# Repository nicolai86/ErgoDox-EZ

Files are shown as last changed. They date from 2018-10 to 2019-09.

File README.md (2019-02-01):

# ErgoDox-EZ

[ErgoDox EZ](https://ergodox-ez.com/) LED mod to convert your regular ErgoDox EZ into an ErgoDox EZ shine.  
The total cost for this mod is about about 40 CAD (~30 CAD for PCBs, ~10 CAD for components)

## Instructions

To build this mod you need to assemble two LED strips, and one I2C bridge. The LED strips are installed on both sides. The right hand LED strip is directly connected to the main PCB. The left hand LED strip requires an I2C bridge to function.

## Firmware

Once you've connected your Atmega168 you can compile the firmware and flash your microcontroller with the included makefile:

```
$ make build
$ make flash
```

The makefile is setup to use the AVR ISP MKII.

## LED strip

You will need to LED pcbs to build this mod. The LED strips are identical for both sides.

### List of materials

| Component | Amount | Notes |
|---|:---:|---:|
| RGBW6812  | 30 | 15 per side; Can be ordered at Aliexpress |
| 3-pin micro JST connector | 1 | right hand connector to main PCB |

The gerber files, eagle project schematics and board files are included in the led-strip folder.

### Assembly

The LED strip assembly needs to be done twice, once for each half. For each side:

1. Solder all 15 RGBW SK6812 LEDs 
2. Solder the cables according to the marks

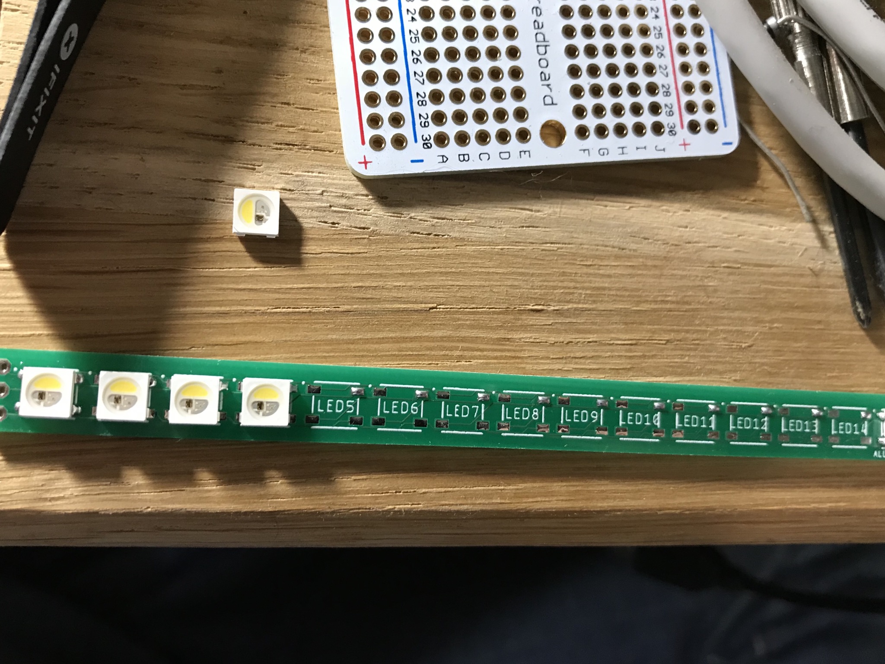
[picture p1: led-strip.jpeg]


For the right hand you can solder the cables to the keyboard, or use a 3-pin micro JST connector instead.
The left hand needs to be connected to an I2C bridge:

## I2C bridge

### List of materials

| Component | Amount | Notes |
|---|:---:|---:|
| atmega168pa-au  | 1 | Required to decode I2C traffic |
| 0805 22pF cap | 2 | |
| 0805 10uF cap | 1 | |
| 0805 10K resistor | 3 | |
| CSM-7X-DU 16Mhz oscillator | 1 | |
| 6 pin AVR ISP connector | 1 | |
| 4-pin micro JST connector | 1 | left hand connector to main PCB |

The gerber files, eagle project schematics and board files are included in the i2c-bride folder.

## Assembly

1. Solder the Atmega168p. Make sure to align the dark circle with the PCB properly. I've used SMD solder paste to place a film over all pins, solder one pin at a time.
2. Solder the 2 22pF caps, C3 and C2.
3. Solder the oscillator. 
4. Solder the 10uF cap.
5. Solder the 3 10k res.
6. Solder the jack. Note that you'll need to desolder it after flashing, or cut them off.

The left hand will look like this after soldering:

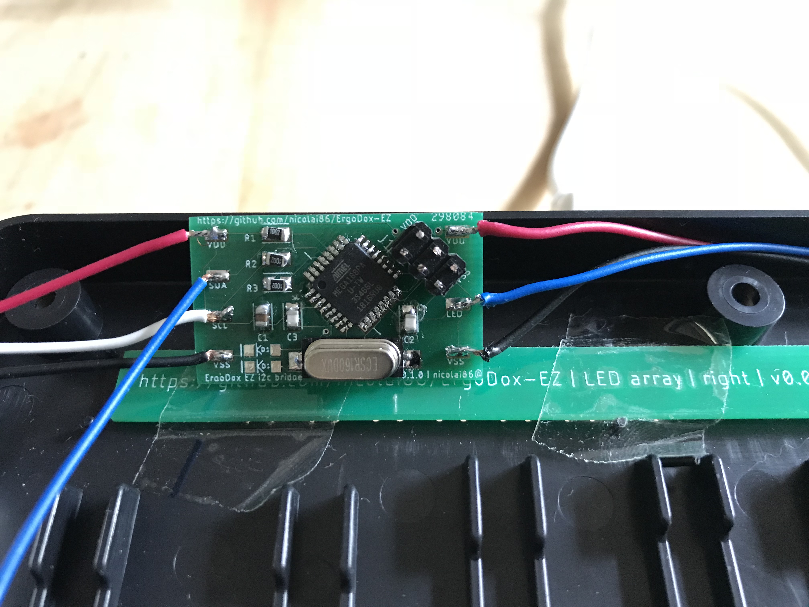
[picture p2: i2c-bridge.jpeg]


check out [KeebTalk](https://www.keebtalk.com/t/did-anybody-try-to-mod-their-ergodox-ez-with-a-custom-led-array/2286) for more images.

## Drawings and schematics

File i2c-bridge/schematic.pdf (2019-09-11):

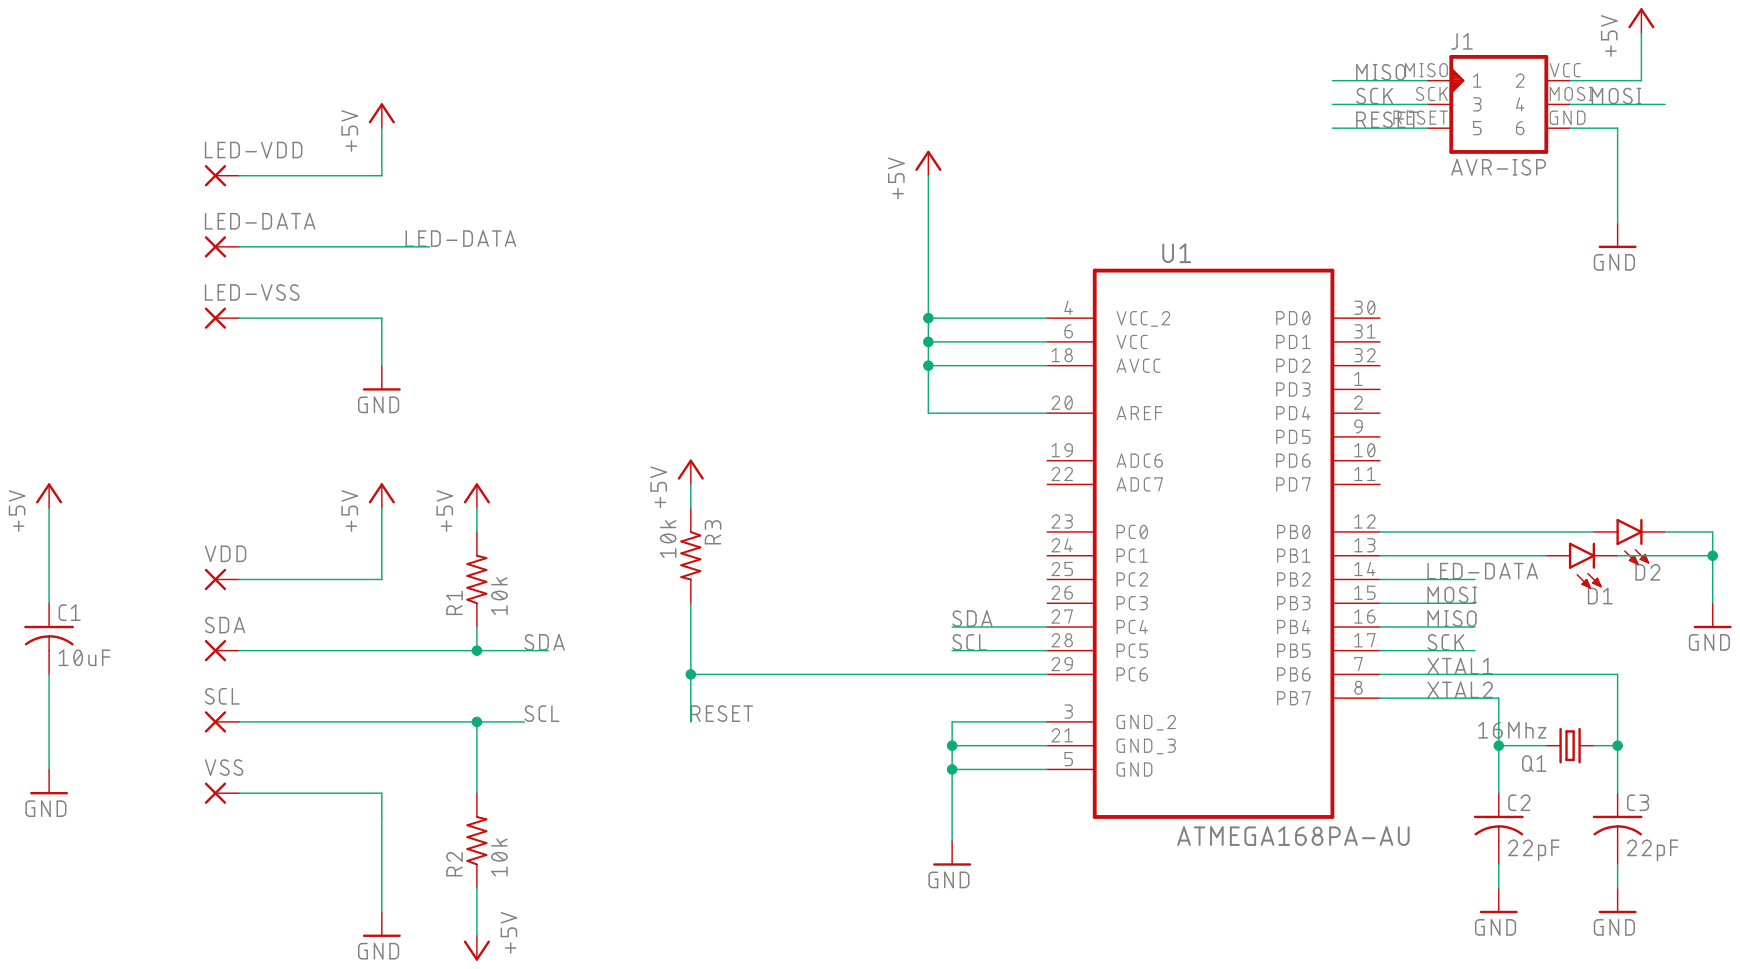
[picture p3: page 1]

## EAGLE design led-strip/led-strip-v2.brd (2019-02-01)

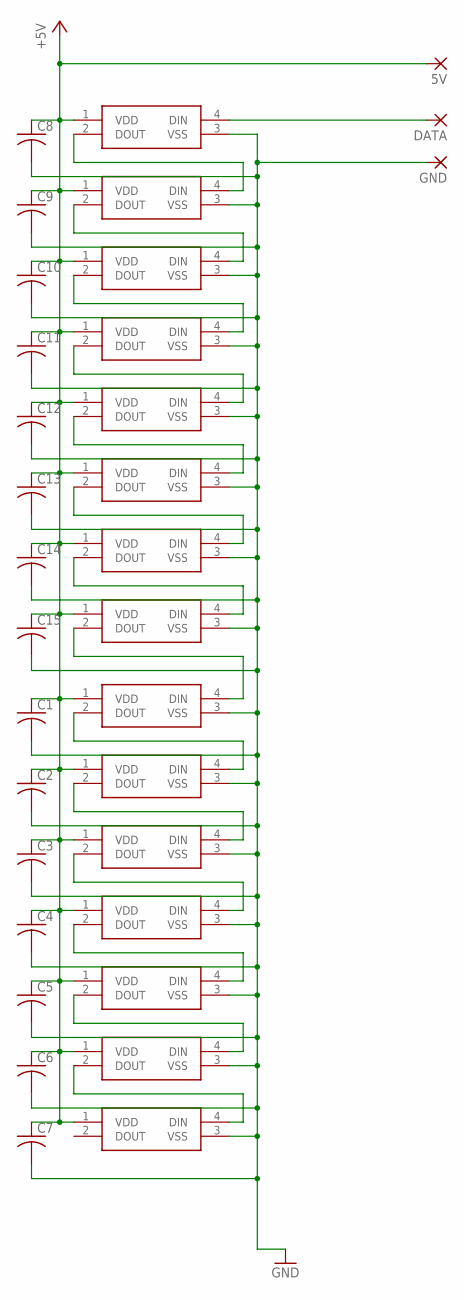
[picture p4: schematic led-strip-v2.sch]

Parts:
5V: 1,6/0,8
C1, C2, C3, C4, C5, C6, C7, C8, C9, C10, C11, C12, C13, C14, C15: C-USC0805; C0805
DATA: 1,6/0,8
GND: 1,6/0,8
LED1, LED2, LED3, LED4, LED5, LED6, LED7, LED8, LED9, LED10, LED11, LED12, LED13, LED14, LED15: 1655; WS2812B_1

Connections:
+5V: 5V.1, C1.1, C2.1, C3.1, C4.1, C5.1, C6.1, C7.1, C8.1, C9.1, C10.1, C11.1, C12.1, C13.1, C14.1, C15.1, LED1.1 (VDD), LED2.1 (VDD), LED3.1 (VDD), LED4.1 (VDD), LED5.1 (VDD), LED6.1 (VDD), LED7.1 (VDD), LED8.1 (VDD), LED9.1 (VDD), LED10.1 (VDD), LED11.1 (VDD), LED12.1 (VDD), LED13.1 (VDD), LED14.1 (VDD), LED15.1 (VDD)
DATA-IN: DATA.1, LED1.4 (DIN)
GND: C1.2, C2.2, C3.2, C4.2, C5.2, C6.2, C7.2, C8.2, C9.2, C10.2, C11.2, C12.2, C13.2, C14.2, C15.2, GND.1, LED1.3 (VSS), LED2.3 (VSS), LED3.3 (VSS), LED4.3 (VSS), LED5.3 (VSS), LED6.3 (VSS), LED7.3 (VSS), LED8.3 (VSS), LED9.3 (VSS), LED10.3 (VSS), LED11.3 (VSS), LED12.3 (VSS), LED13.3 (VSS), LED14.3 (VSS), LED15.3 (VSS)
unnamed: LED1.2 (DOUT), LED2.4 (DIN)
unnamed: LED2.2 (DOUT), LED3.4 (DIN)
unnamed: LED3.2 (DOUT), LED4.4 (DIN)
unnamed: LED4.2 (DOUT), LED5.4 (DIN)
unnamed: LED5.2 (DOUT), LED6.4 (DIN)
unnamed: LED6.2 (DOUT), LED7.4 (DIN)
unnamed: LED7.2 (DOUT), LED8.4 (DIN)
unnamed: LED8.2 (DOUT), LED9.4 (DIN)
unnamed: LED9.2 (DOUT), LED10.4 (DIN)
unnamed: LED10.2 (DOUT), LED11.4 (DIN)
unnamed: LED11.2 (DOUT), LED12.4 (DIN)
unnamed: LED12.2 (DOUT), LED13.4 (DIN)
unnamed: LED13.2 (DOUT), LED14.4 (DIN)
unnamed: LED14.2 (DOUT), LED15.4 (DIN)

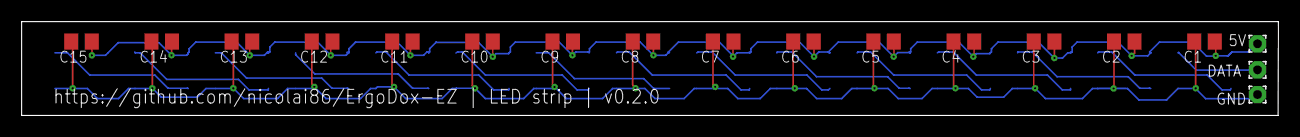
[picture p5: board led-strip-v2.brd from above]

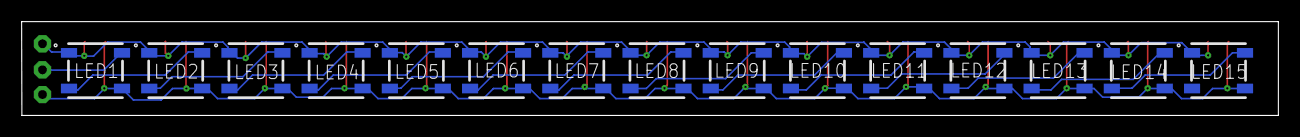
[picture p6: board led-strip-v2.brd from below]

Board: 2 copper layers, 116.3 x 8.7 mm, 33 parts (15 on the bottom side), 17 nets.

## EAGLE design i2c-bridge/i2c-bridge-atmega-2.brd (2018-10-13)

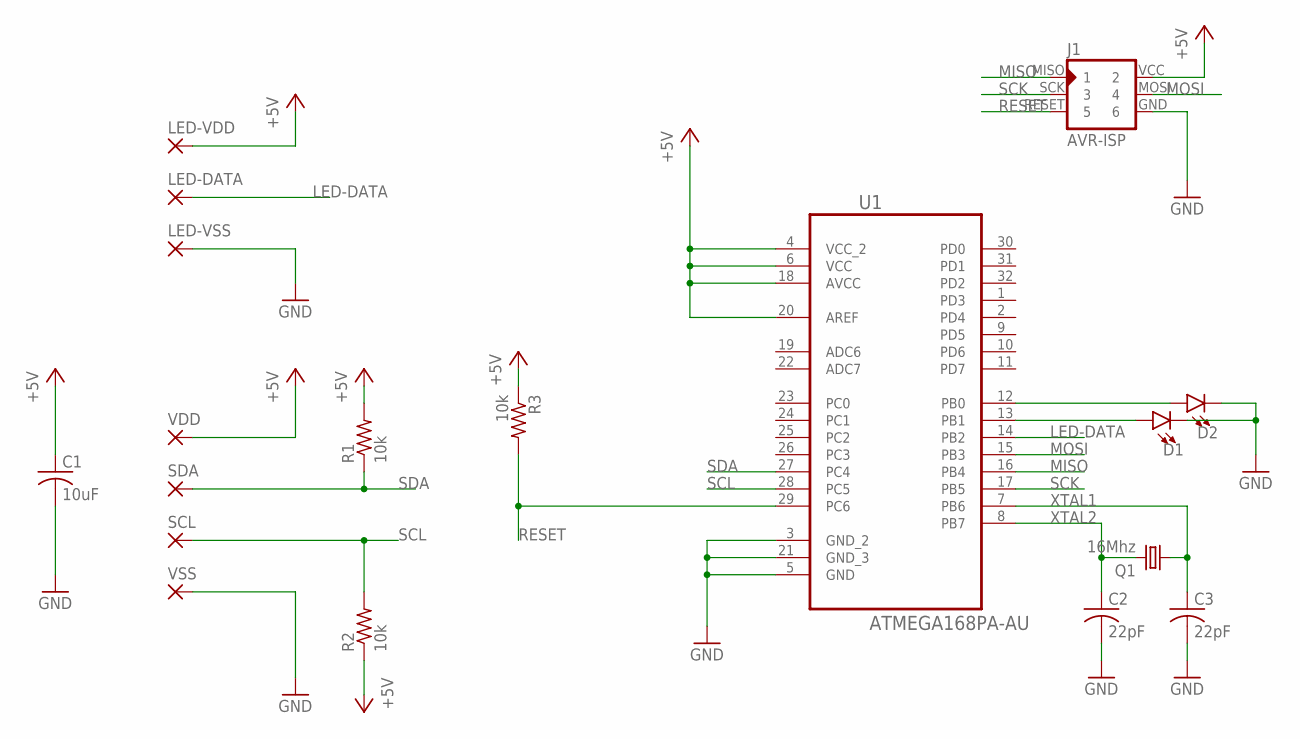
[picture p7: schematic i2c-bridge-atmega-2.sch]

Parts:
C1: 10uF; C0805
C2, C3: 22pF; C0805
D1, D2: WHITE; LED-1206
J1: AVR-ISP; AVR-ISP-6PIN-SMAILL-SILK
LED-DATA: SMD2; SMD1,27-2,54
LED-VDD: SMD2; SMD1,27-2,54
LED-VSS: SMD2; SMD1,27-2,54
Q1: 16Mhz; CSM-7X-DU
R1, R2, R3: 10k; R0805
SCL: SMD2; SMD1,27-2,54
SDA: SMD2; SMD1,27-2,54
U1: ATMEGA168PA-AU; QFP80P900X900X120-32N
VDD: SMD2; SMD1,27-2,54
VSS: SMD2; SMD1,27-2,54

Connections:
+5V: C1.1, J1.VCC (2), LED-VDD.1, R1.2, R2.1, R3.1, U1.4 (VCC_2), U1.6 (VCC), U1.18 (AVCC), U1.20 (AREF), VDD.1
GND: C1.2, C2.2, C3.2, D1.C, D2.C, J1.GND (6), LED-VSS.1, U1.3 (GND_2), U1.5 (GND), U1.21 (GND_3), VSS.1
LED-DATA: LED-DATA.1, U1.14 (PB2)
MISO: J1.MISO (1), U1.16 (PB4)
MOSI: J1.MOSI (4), U1.15 (PB3)
unnamed: D1.A, U1.13 (PB1)
unnamed: D2.A, U1.12 (PB0)
RESET: J1.RESET (5), R3.2, U1.29 (PC6)
SCK: J1.SCK (3), U1.17 (PB5)
SCL: R2.2, SCL.1, U1.28 (PC5)
SDA: R1.1, SDA.1, U1.27 (PC4)
XTAL1: C3.1, Q1.1, U1.7 (PB6)
XTAL2: C2.1, Q1.2, U1.8 (PB7)

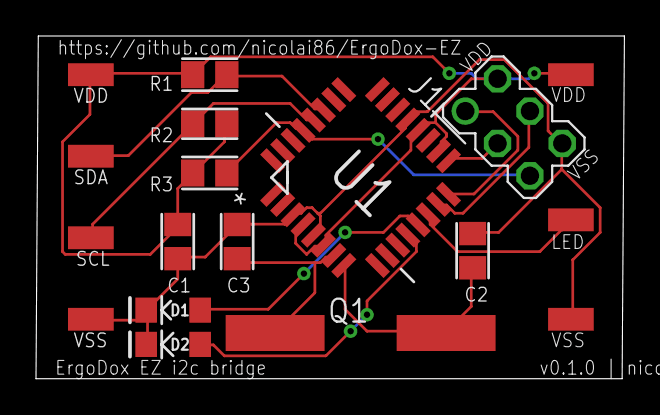
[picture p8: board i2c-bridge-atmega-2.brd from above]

Board: 2 copper layers, 32.7 x 19.0 mm, 18 parts (0 on the bottom side), 13 nets.

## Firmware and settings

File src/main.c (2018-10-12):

#define F_CPU 16000000UL   // 16Mhz
#define I2C_ADDR 0b1000010 // 0x84h

#define ws2812_resettime 300
#define ws2812_port B
#define ws2812_pin 2

#define RGBW_COUNT 15
#define TWI_BUFFER_SIZE RGBW_COUNT * 4 // 15 RGBW leds, 4 byte each

#include <util/delay.h>
#include <avr/interrupt.h>
#include <stdint.h>

#include "TWI_slave.h"
#include "light_ws2812.h"

int main()
{
    TWI_Slave_Initialise(I2C_ADDR << 1);
    TWI_Start_Transceiver();
    DDRB |= _BV(ws2812_pin);
    sei();

    uint8_t rxMessage[TWI_BUFFER_SIZE];

    while(1) {
        if (!TWI_Transceiver_Busy() && TWI_statusReg.RxDataInBuf)
        {
            TWI_Get_Data_From_Transceiver(rxMessage, TWI_BUFFER_SIZE);
            ws2812_sendarray((uint8_t *)rxMessage, TWI_BUFFER_SIZE);
            TWI_Start_Transceiver();
        }
        
        if (TIFR1 & _BV(OCF1A))
        {
            TIFR1 = _BV(OCF1A);
        }
    }
}

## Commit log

2018-10-12 add atmega168 i2c source
    the atmega168 acts as the FPGA used in the original ErgoDox EZ shine.
    It reads the RGBW data via I2C and sets it to the LEDs once all data is
    received.
2018-10-13 add eagle project files and gerber exports
    [i2c-bridge-atmega-2.brd, i2c-bridge-atmega-2.sch, led-strip-v2.brd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]
2018-10-27 update makefile for SMD PCB
    the SMD one uses the atmega168p
2018-10-27 add assembly instructions
2019-02-01 add v0.2.0 with decoupling capacitors between leds
    [led-strip-v2.brd, led-strip-v2.sch]
2019-09-11 add schematic

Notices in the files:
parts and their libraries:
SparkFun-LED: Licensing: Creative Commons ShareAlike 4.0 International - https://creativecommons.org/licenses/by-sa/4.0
